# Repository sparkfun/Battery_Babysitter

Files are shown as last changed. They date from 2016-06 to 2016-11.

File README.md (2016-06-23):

SparkFun Battery Babysitter
========================================

SparkFun Battery Babysitter (https://www.sparkfun.com/products/13777)

[*SparkFun Battery Babysitter (PRT-13777)*](https://www.sparkfun.com/products/13777)

The [SparkFun Battery Babysitter](https://www.sparkfun.com/products/13777) is an all-in-one single-cell lithium polymer (LiPo) battery manager. It’s half **battery-charger**, half **battery monitor**, and it’s all you’ll ever need to keep your battery-powered project running safely and extensively.

The Battery Babysitter features a pair of Texas Instruments LiPo-management IC’s: a [BQ24075 battery charger](http://www.ti.com/product/BQ24075) and a [BQ27441-G1A fuel gauge](http://www.ti.com/product/BQ27441-G1). The BQ24075 supports adjustable charge rates up to 1.5A, as well as USB-compliant 100mA and 500mA options. It also features power-path management, guaranteeing reliable power to your project.

The self-calibrating, I2C-based BQ27441-G1A measures your battery’s voltage to estimate its charge percentage and remaining capacity. The chip is also hooked up to a current-sensing resistor, which allows it to measure current and power! It’s a handy IC to have, especially if you ever need to keep an extra eye on your project’s power draw.

Repository Contents
-------------------

* **/Documentation** - Data sheets, additional product information
* **/Hardware** - Eagle design files (.brd, .sch)
* **/Libraries** - Libraries for use with the Battery Babysitter
* **/Production** - Production panel files (.brd)

Documentation
--------------
* **[BQ27441 LiPo Fuel Gauge Arduino Library](https://github.com/sparkfun/SparkFun_BQ27441_Arduino_Library)** - Arduino library for the Battery Babysitter's BQ27441-G1A LiPo Fuel Gauge.
* **[Hookup Guide](https://learn.sparkfun.com/tutorials/battery-babysitter-hookup-guide)** - Basic hookup guide for the Battery Babysitter.
* **[SparkFun Fritzing repo](https://github.com/sparkfun/Fritzing_Parts)** - Fritzing diagrams for SparkFun products.
* **[SparkFun 3D Model repo](https://github.com/sparkfun/3D_Models)** - 3D models of SparkFun products. 
* **[SparkFun Graphical Datasheets](https://github.com/sparkfun/Graphical_Datasheets)** -Graphical Datasheets for various SparkFun products.

Product Versions
----------------
* [Battery Babysitter v1.0 (PRT-13777)](https://www.sparkfun.com/products/13777)- Initial release of the SparkFun Battery Babysitter.

Version History
---------------
* [1.0](https://github.com/sparkfun/Battery_Babysitter/releases/tag/V_1.0) - v1.0 Hardware release

License Information
-------------------

This product is _**open source**_! 

Please review the LICENSE.md file for license information. 

If you have any questions or concerns on licensing, please contact techsupport@sparkfun.com.

Distributed as-is; no warranty is given.

- Your friends at SparkFun.

_<COLLABORATION CREDIT>_

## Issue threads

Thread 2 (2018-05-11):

EN1 & EN2 Operation Description

dwgibbons, 2018-05-11:
The operational description of EN1 and EN2 appears to be wrong in both the documentation and schematic. The datasheet describes their use as "EN1 and EN2 control the maximum input current" on page 5. (ILIM, not ISET).

I've been staring at datasheets a lot longer than usual today. Please let me know if I'm wrong.

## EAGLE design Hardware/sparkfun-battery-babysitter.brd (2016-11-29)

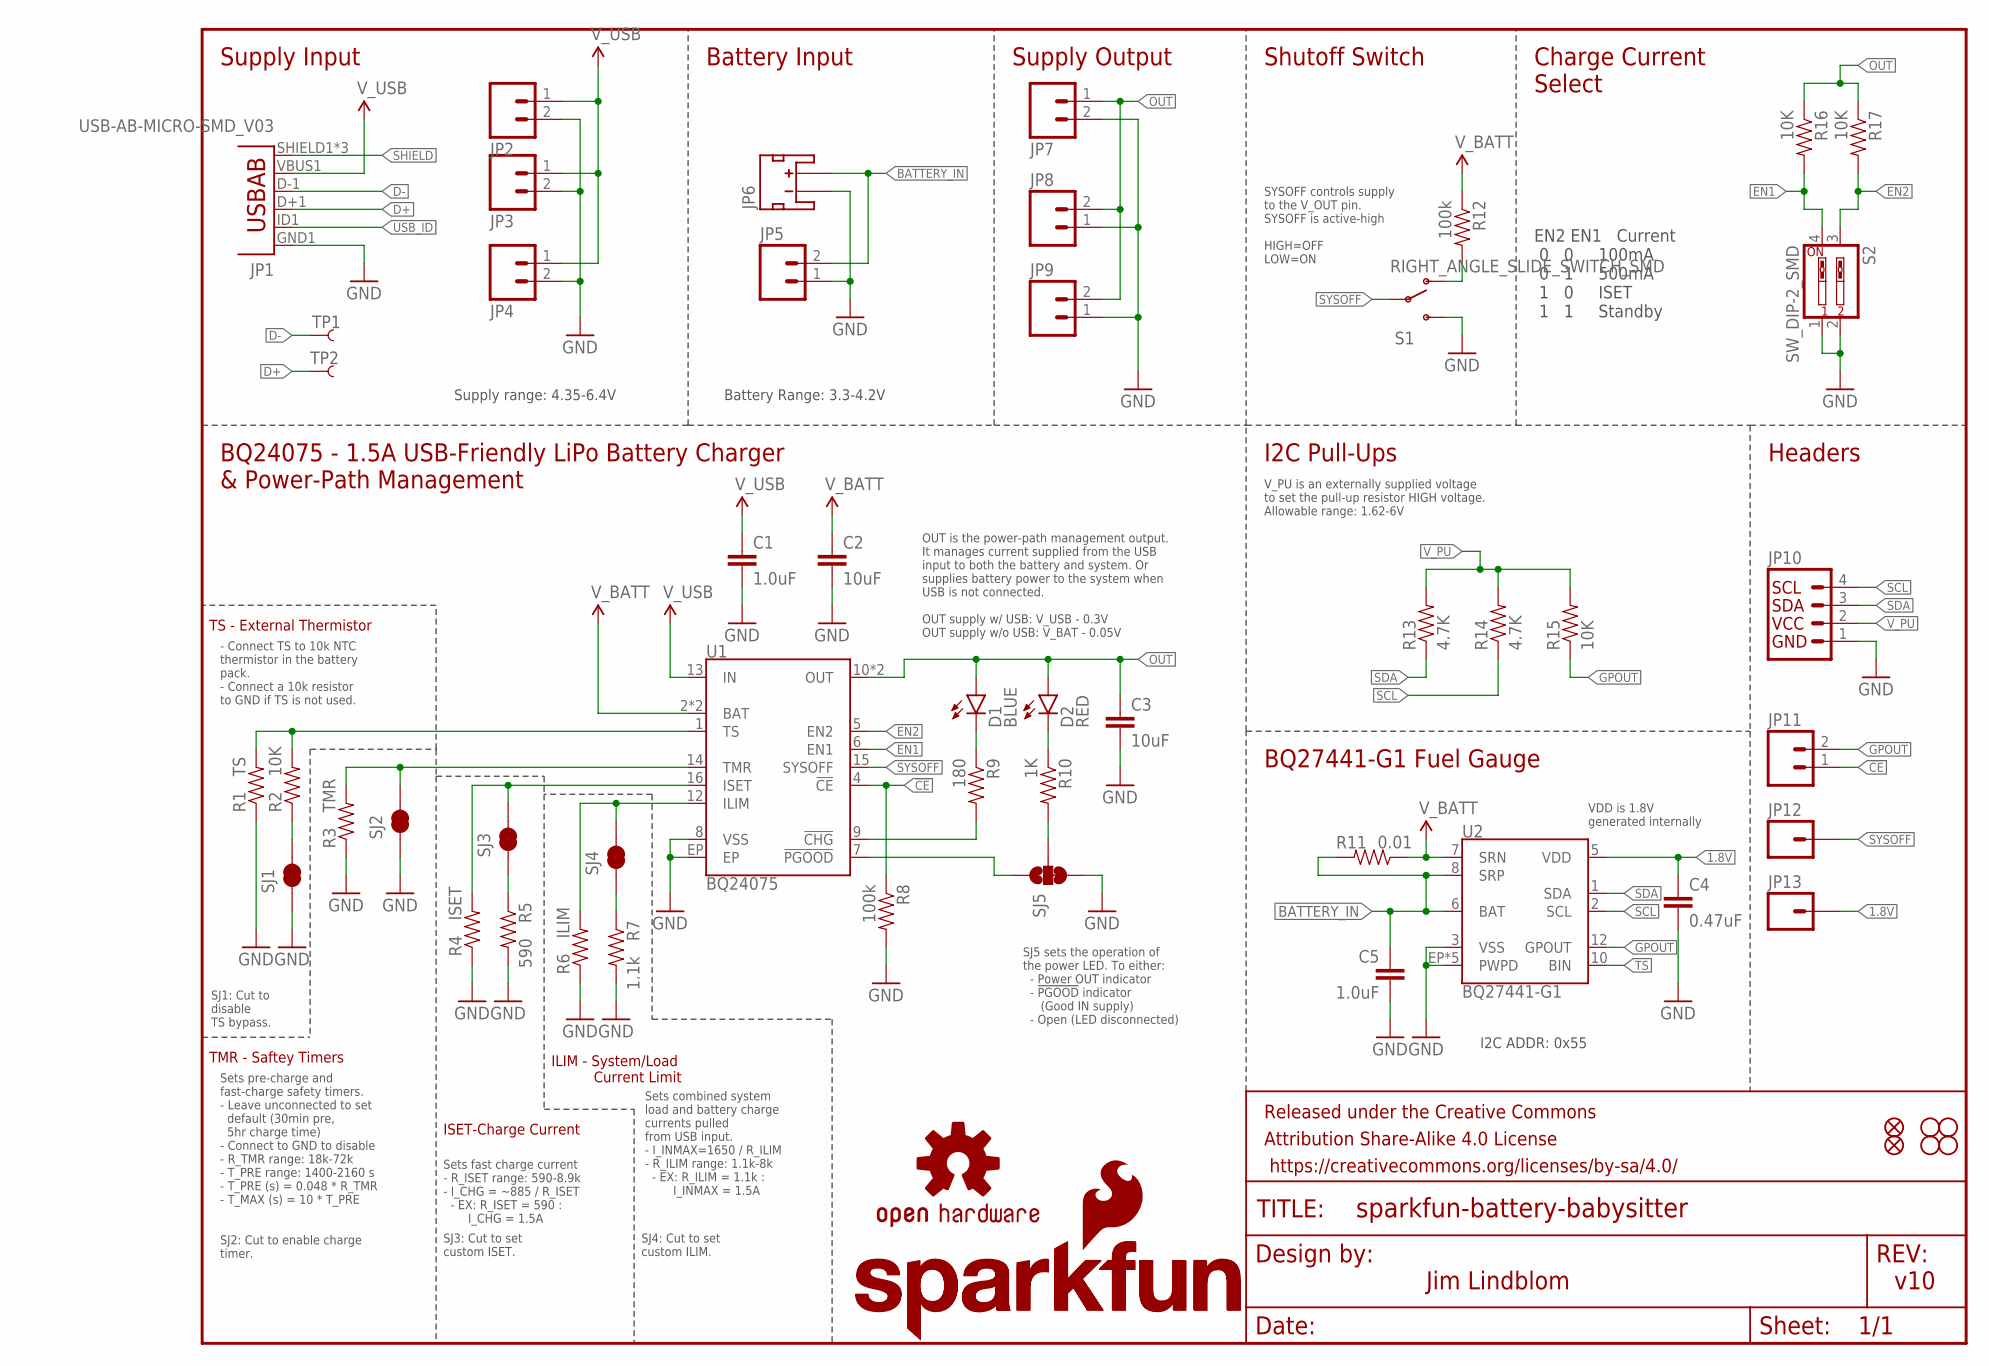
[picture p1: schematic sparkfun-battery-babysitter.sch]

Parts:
C1: 1.0uF; 1206-CAP
C2, C3: 10uF; 0805-CAP
C4: 0.47uF; 0603-CAP
C5: 1.0uF; 0603-CAP
D1: BLUE; LED-0603
D2: RED; LED-0603
FID1, FID2: FIDUCIAL1X2; FIDUCIAL-1X2
FRAME1: FRAME-LETTER; CREATIVE_COMMONS
JP1: USB-AB-MICRO-SMD_V03
JP2, JP4, JP5, JP8, JP11: M021X02_NO_SILK; 1X02_NO_SILK
JP3, JP7: M023.5MM-NO_SILK; SCREWTERMINAL-3.5MM-2-NS
JP6: JST_2MM_MALE; JST-2-SMD
JP9: M02-JST-2-PTH-NO_SILK; JST-2-PTH-NS
JP10: I2C_STANDARD_NO_SILK; 1X04_NO_SILK
JP12, JP13: M01PTH_NO_SILK_YES_STOP; 1X01_NO_SILK
LOGO1: SFE_LOGO_NAME.1_INCH; SFE_LOGO_NAME_.1
LOGO2: SFE_LOGO_NAME_FLAME.1_INCH; SFE_LOGO_NAME_FLAME_.1
LOGO3: OSHW-LOGOS; OSHW-LOGO-S
R1: TS; 1/6W-RES
R2, R15, R16, R17: 10K; 0603-RES
R3: TMR; 1/6W-RES
R4: ISET; 1/6W-RES
R5: 590; 0603-RES
R6: ILIM; 1/6W-RES
R7: 1.1k; 0603-RES
R8, R12: 100k; 0603-RES
R9: 180; 0603-RES
R10: 1K; 0603-RES
R11: 0.01; 1206
R13, R14: 4.7K; 0603-RES
S1: RIGHT_ANGLE_SLIDE_SWITCH_SMD; SWITCH-SPST-SMD-A
S2: SW_DIP-2_SMD; DIPSWITCH-02-50MIL
SJ1, SJ2, SJ3, SJ4: JUMPER-PAD-2-NC_BY_TRACE; PAD-JUMPER-2-NC_BY_TRACE_YES_SILK
SJ5: JUMPER-PAD-3-2OF3_NC_BY_TRACE_SMALL; PAD-JUMPER-3-2OF3_NC_BY_TRACE_YES_SILK_FULL_BOX
STANDOFF1, STANDOFF2, STANDOFF3, STANDOFF4: STAND-OFF
TP1, TP2: TEST-POINT3X4; PAD.03X.04
U1: BQ24075; PVQFN-N16
U2: BQ27441-G1; PDSO-N12

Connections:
1.8V: C4.1, JP13.1, U2.5 (VDD)
!CE!: JP11.1, R8.1, U1.4 (!CE!)
!CHG!: R9.2, U1.9 (!CHG!)
!PGOOD!: SJ5.1, U1.7 (!PGOOD!)
BATTERY_IN: C5.1, JP5.2, JP6.2 (+), R11.2, U2.6 (BAT), U2.8 (SRP)
D+: JP1.D+1 (D+), TP2.P$1
D-: JP1.D-1 (D-), TP1.P$1
EN1: R16.2, S2.4, U1.6 (EN1)
EN2: R17.2, S2.3, U1.5 (EN2)
GND: C1.2, C2.2, C3.2, C4.2, C5.2, JP1.GND1 (GND), JP2.2, JP3.2, JP4.2, JP5.1, JP6.1 (-), JP7.2, JP8.1, JP9.1, JP10.1, R1.1, R3.1, R4.1, R5.2, R6.1, R7.2, R8.2, S1.3 (S), S2.1, S2.2, SJ1.1, SJ2.1, SJ5.3, U1.8 (VSS), U1.EP, U2.3 (VSS), U2.EP (PWPD), U2.EP1 (PWPD), U2.EP2 (PWPD), U2.EP3 (PWPD), U2.EP4 (PWPD)
GPOUT: JP11.2, R15.1, U2.12 (GPOUT)
ILIM: R6.2, SJ4.2, U1.12 (ILIM)
ISET: R4.2, SJ3.2, U1.16 (ISET)
unnamed: R2.1, SJ1.2
unnamed: R7.1, SJ4.1
unnamed: R5.1, SJ3.1
unnamed: R12.2, S1.1 (O)
unnamed: R10.2, SJ5.2
unnamed: D1.C, R9.1
unnamed: D2.C, R10.1
OUT: C3.1, D1.A, D2.A, JP7.1, JP8.2, JP9.2, R16.1, R17.1, U1.10 (OUT), U1.11 (OUT)
SCL: JP10.4, R14.1, U2.2 (SCL)
SDA: JP10.3, R13.1, U2.1 (SDA)
SHIELD: JP1.SHIELD1 (SHIELD), JP1.SHIELD2 (SHIELD), JP1.SHIELD3 (SHIELD)
SYSOFF: JP12.1, S1.2, U1.15 (SYSOFF)
TMR: R3.2, SJ2.2, U1.14 (TMR)
TS: R1.2, R2.2, U1.1 (TS), U2.10 (BIN)
USB_ID: JP1.ID1 (USBID)
V_BATT: C2.1, R11.1, R12.1, U1.2 (BAT), U1.3 (BAT), U2.7 (SRN)
V_PU: JP10.2, R13.2, R14.2, R15.2
V_USB: C1.1, JP1.VBUS1 (VBUS), JP2.1, JP3.1, JP4.1, U1.13 (IN)

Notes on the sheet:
EN2 EN1 Current 0 0 100mA 0 1 500mA 1 0 ISET 1 1 Standby
Sets fast charge current - R_ISET range: 590-8.9k - I_CHG = ~885 / R_ISET - EX: R_ISET = 590 : I_CHG = 1.5A
Sets combined system load and battery charge currents pulled from USB input. - I_INMAX=1650 / R_ILIM - R_ILIM range: 1.1k-8k - EX: R_ILIM = 1.1k : I_INMAX = 1.5A
Supply Input
Battery Input
Supply Output
Shutoff Switch
Charge Current Select
BQ24075 - 1.5A USB-Friendly LiPo Battery Charger & Power-Path Management
I2C Pull-Ups
BQ27441-G1 Fuel Gauge
Headers
Jim Lindblom
v10
SYSOFF controls supply to the V_OUT pin. SYSOFF is active-high HIGH=OFF LOW=ON
SJ1: Cut to disable TS bypass.
SJ3: Cut to set custom ISET.
SJ4: Cut to set custom ILIM.
ILIM - System/Load Current Limit
ISET-Charge Current
TMR - Saftey Timers
Sets pre-charge and fast-charge safety timers. - Leave unconnected to set default (30min pre, 5hr charge time) - Connect to GND to disable - R_TMR range: 18k-72k - T_PRE range: 1400-2160 s - T_PRE (s) = 0.048 * R_TMR - T_MAX (s) = 10 * T_PRE
SJ2: Cut to enable charge timer.
TS - External Thermistor
- Connect TS to 10k NTC thermistor in the battery pack. - Connect a 10k resistor to GND if TS is not used.
V_PU is an externally supplied voltage to set the pull-up resistor HIGH voltage. Allowable range: 1.62-6V
Supply range: 4.35-6.4V
VDD is 1.8V generated internally
OUT is the power-path management output. It manages current supplied from the USB input to both the battery and system. Or supplies battery power to the system when USB is not connected. OUT supply w/ USB: V_USB - 0.3V OUT supply w/o USB: V_BAT - 0.05V
I2C ADDR: 0x55
SJ5 sets the operation of the power LED. To either: - Power OUT indicator - !PGOOD! indicator (Good IN supply) - Open (LED disconnected)
Battery Range: 3.3-4.2V

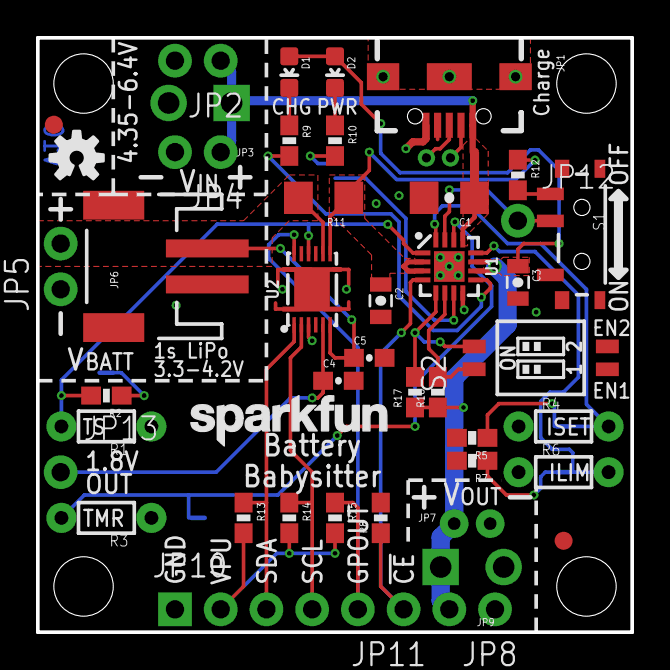
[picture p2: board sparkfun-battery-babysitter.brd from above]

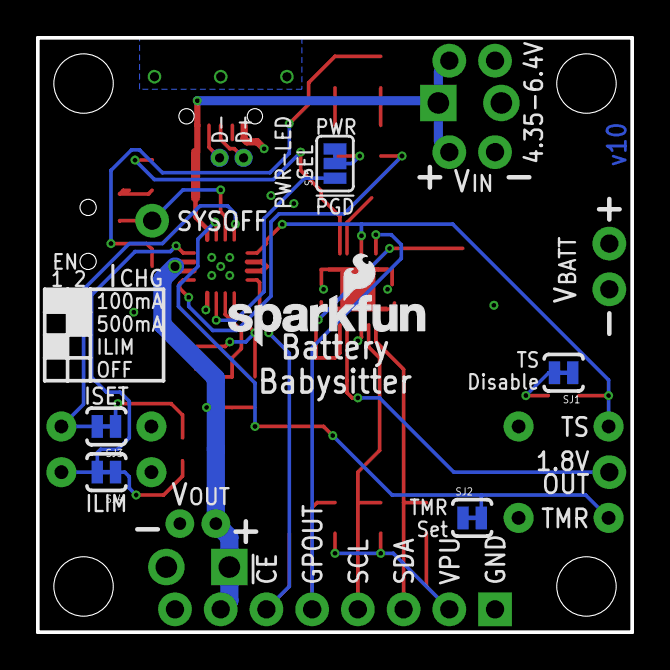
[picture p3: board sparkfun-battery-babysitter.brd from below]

Board: 2 copper layers, 33.0 x 33.0 mm, 58 parts (8 on the bottom side), 30 nets.

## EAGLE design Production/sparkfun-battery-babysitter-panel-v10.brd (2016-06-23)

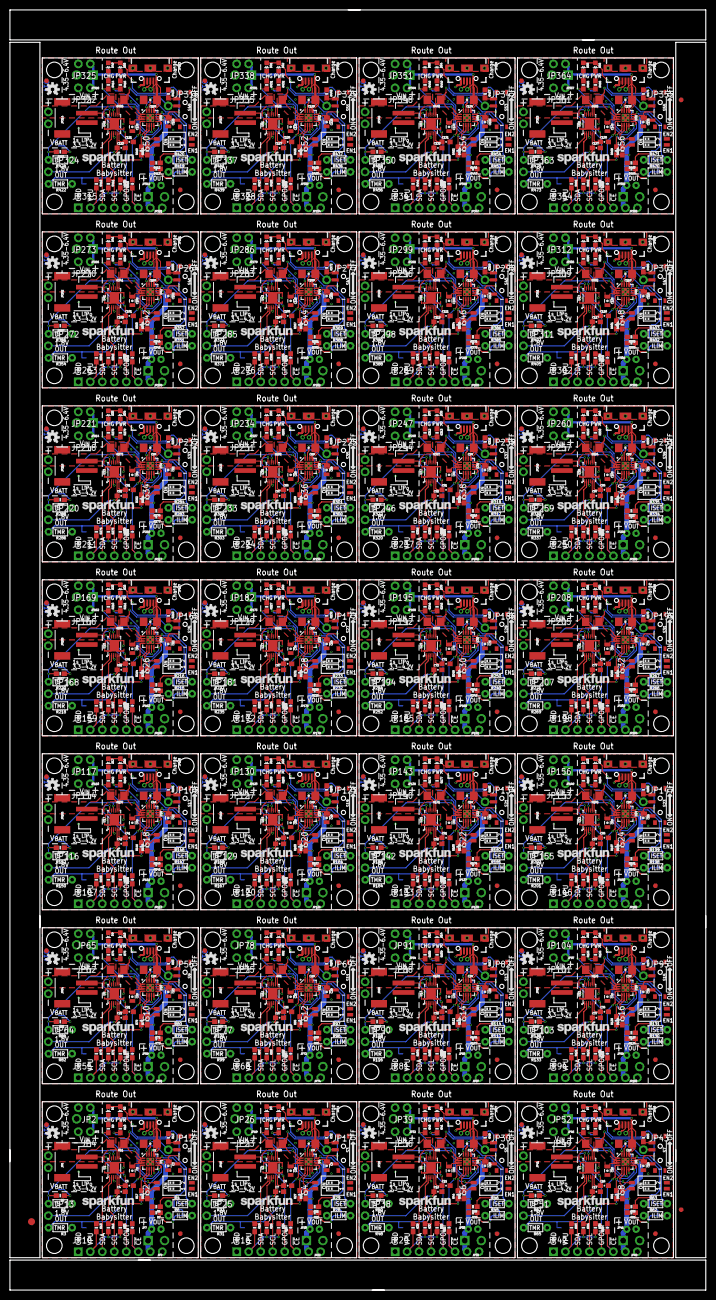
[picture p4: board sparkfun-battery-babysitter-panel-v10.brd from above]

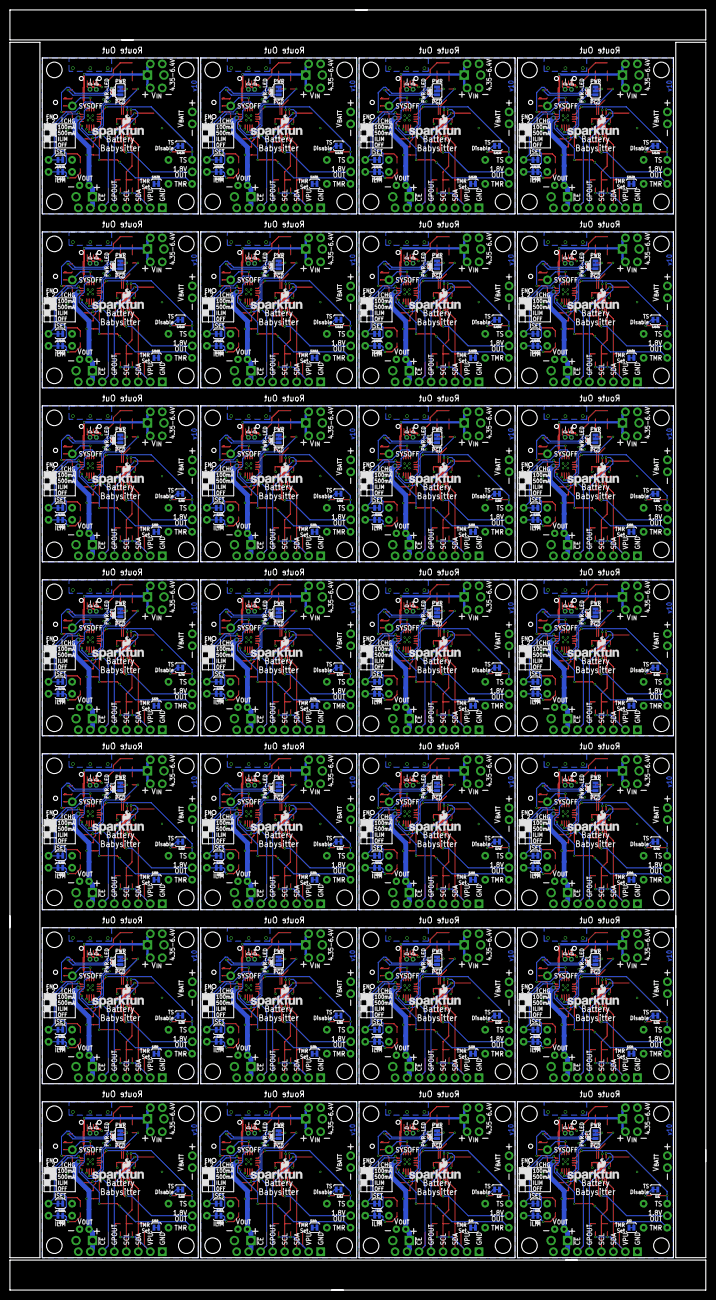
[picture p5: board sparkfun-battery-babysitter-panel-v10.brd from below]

Board: 2 copper layers, 147.3 x 271.0 mm, 1599 parts (224 on the bottom side), 840 nets.

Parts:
C1, C9, C14, C19, C24, C29, C34, C39, C44, C49, C54, C59, C64, C69, C74, C79, C84, C89, C94, C99, C104, C109, C114, C119, C124, C129, C134, C139: 1.0uF; 1206-CAP
C2, C3, C8, C10, C13, C15, C18, C20, C23, C25, C28, C30, C33, C35, C38, C40, C43, C45, C48, C50, C53, C55, C58, C60, C63, C65, C68, C70, C73, C75, C78, C80, C83, C85, C88, C90, C93, C95, C98, C100, C103, C105, C108, C110, C113, C115, C118, C120, C123, C125, C128, C130, C133, C135, C138, C140: 10uF; 0805-CAP
C4, C7, C12, C17, C22, C27, C32, C37, C42, C47, C52, C57, C62, C67, C72, C77, C82, C87, C92, C97, C102, C107, C112, C117, C122, C127, C132, C137: 0.47uF; 0603-CAP
C5, C6, C11, C16, C21, C26, C31, C36, C41, C46, C51, C56, C61, C66, C71, C76, C81, C86, C91, C96, C101, C106, C111, C116, C121, C126, C131, C136: 1.0uF; 0603-CAP
D1, D3, D5, D7, D9, D11, D13, D15, D17, D19, D21, D23, D25, D27, D29, D31, D33, D35, D37, D39, D41, D43, D45, D47, D49, D51, D53, D55: BLUE; LED-0603
D2, D4, D6, D8, D10, D12, D14, D16, D18, D20, D22, D24, D26, D28, D30, D32, D34, D36, D38, D40, D42, D44, D46, D48, D50, D52, D54, D56: RED; LED-0603
E$1: FIDUCIAL-1.5X3
E$5, E$6: FIDUCIAL-1X2
FID1, FID2, FID3, FID4, FID5, FID6, FID7, FID8, FID9, FID10, FID11, FID12, FID13, FID14, FID15, FID16, FID17, FID18, FID19, FID20, FID21, FID22, FID23, FID24, FID25, FID26, FID27, FID28, FID29, FID30, FID31, FID32, FID33, FID34, FID35, FID36, FID37, FID38, FID39, FID40, FID41, FID42, FID43, FID44, FID45, FID46, FID47, FID48, FID49, FID50, FID51, FID52, FID53, FID54, FID55, FID56: FIDUCIAL1X2; FIDUCIAL-1X2
JP1, JP14, JP27, JP40, JP53, JP66, JP79, JP92, JP105, JP118, JP131, JP144, JP157, JP170, JP183, JP196, JP209, JP222, JP235, JP248, JP261, JP274, JP287, JP300, JP313, JP326, JP339, JP352: USB-AB-MICRO-SMD_V03
JP2, JP4, JP5, JP8, JP11, JP18, JP21, JP23, JP24, JP26, JP31, JP34, JP36, JP37, JP39, JP44, JP47, JP49, JP50, JP52, JP57, JP60, JP62, JP63, JP65, JP70, JP73, JP75, JP76, JP78, JP83, JP86, JP88, JP89, JP91, JP96, JP99, JP101, JP102, JP104, JP109, JP112, JP114, JP115, JP117, JP122, JP125, JP127, JP128, JP130, JP135, JP138, JP140, JP141, JP143, JP148, JP151, JP153, JP154, JP156, JP161, JP164, JP166, JP167, JP169, JP174, JP177, JP179, JP180, JP182, JP187, JP190, JP192, JP193, JP195, JP200, JP203, JP205, JP206, JP208, JP213, JP216, JP218, JP219, JP221, JP226, JP229, JP231, JP232, JP234, JP239, JP242, JP244, JP245, JP247, JP252, JP255, JP257, JP258, JP260, JP265, JP268, JP270, JP271, JP273, JP278, JP281, JP283, JP284, JP286, JP291, JP294, JP296, JP297, JP299, JP304, JP307, JP309, JP310, JP312, JP317, JP320, JP322, JP323, JP325, JP330, JP333, JP335, JP336, JP338, JP343, JP346, JP348, JP349, JP351, JP356, JP359, JP361, JP362, JP364: 1X02_NO_SILK
JP3, JP7, JP19, JP20, JP32, JP33, JP45, JP46, JP58, JP59, JP71, JP72, JP84, JP85, JP97, JP98, JP110, JP111, JP123, JP124, JP136, JP137, JP149, JP150, JP162, JP163, JP175, JP176, JP188, JP189, JP201, JP202, JP214, JP215, JP227, JP228, JP240, JP241, JP253, JP254, JP266, JP267, JP279, JP280, JP292, JP293, JP305, JP306, JP318, JP319, JP331, JP332, JP344, JP345, JP357, JP358: SCREWTERMINAL-3.5MM-2-NS
JP6, JP15, JP28, JP41, JP54, JP67, JP80, JP93, JP106, JP119, JP132, JP145, JP158, JP171, JP184, JP197, JP210, JP223, JP236, JP249, JP262, JP275, JP288, JP301, JP314, JP327, JP340, JP353: JST-2-SMD
JP9, JP22, JP35, JP48, JP61, JP74, JP87, JP100, JP113, JP126, JP139, JP152, JP165, JP178, JP191, JP204, JP217, JP230, JP243, JP256, JP269, JP282, JP295, JP308, JP321, JP334, JP347, JP360: JST-2-PTH-NS
JP10, JP16, JP29, JP42, JP55, JP68, JP81, JP94, JP107, JP120, JP133, JP146, JP159, JP172, JP185, JP198, JP211, JP224, JP237, JP250, JP263, JP276, JP289, JP302, JP315, JP328, JP341, JP354: 1X04_NO_SILK
JP12, JP13, JP17, JP25, JP30, JP38, JP43, JP51, JP56, JP64, JP69, JP77, JP82, JP90, JP95, JP103, JP108, JP116, JP121, JP129, JP134, JP142, JP147, JP155, JP160, JP168, JP173, JP181, JP186, JP194, JP199, JP207, JP212, JP220, JP225, JP233, JP238, JP246, JP251, JP259, JP264, JP272, JP277, JP285, JP290, JP298, JP303, JP311, JP316, JP324, JP329, JP337, JP342, JP350, JP355, JP363: 1X01_NO_SILK
LOGO1, LOGO4, LOGO7, LOGO10, LOGO13, LOGO16, LOGO19, LOGO22, LOGO25, LOGO28, LOGO31, LOGO34, LOGO37, LOGO40, LOGO43, LOGO46, LOGO49, LOGO52, LOGO55, LOGO58, LOGO61, LOGO64, LOGO67, LOGO70, LOGO73, LOGO76, LOGO79, LOGO82: SFE_LOGO_NAME.1_INCH; SFE_LOGO_NAME_.1
LOGO2, LOGO6, LOGO9, LOGO12, LOGO15, LOGO18, LOGO21, LOGO24, LOGO27, LOGO30, LOGO33, LOGO36, LOGO39, LOGO42, LOGO45, LOGO48, LOGO51, LOGO54, LOGO57, LOGO60, LOGO63, LOGO66, LOGO69, LOGO72, LOGO75, LOGO78, LOGO81, LOGO84: SFE_LOGO_NAME_FLAME.1_INCH; SFE_LOGO_NAME_FLAME_.1
LOGO3, LOGO5, LOGO8, LOGO11, LOGO14, LOGO17, LOGO20, LOGO23, LOGO26, LOGO29, LOGO32, LOGO35, LOGO38, LOGO41, LOGO44, LOGO47, LOGO50, LOGO53, LOGO56, LOGO59, LOGO62, LOGO65, LOGO68, LOGO71, LOGO74, LOGO77, LOGO80, LOGO83: OSHW-LOGOS; OSHW-LOGO-S
R1, R33, R50, R67, R84, R101, R118, R135, R152, R169, R186, R203, R220, R237, R254, R271, R288, R305, R322, R339, R356, R373, R390, R407, R424, R441, R458, R475: TS; 1/6W-RES
R2, R15, R16, R17, R26, R27, R30, R34, R43, R44, R47, R51, R60, R61, R64, R68, R77, R78, R81, R85, R94, R95, R98, R102, R111, R112, R115, R119, R128, R129, R132, R136, R145, R146, R149, R153, R162, R163, R166, R170, R179, R180, R183, R187, R196, R197, R200, R204, R213, R214, R217, R221, R230, R231, R234, R238, R247, R248, R251, R255, R264, R265, R268, R272, R281, R282, R285, R289, R298, R299, R302, R306, R315, R316, R319, R323, R332, R333, R336, R340, R349, R350, R353, R357, R366, R367, R370, R374, R383, R384, R387, R391, R400, R401, R404, R408, R417, R418, R421, R425, R434, R435, R438, R442, R451, R452, R455, R459, R468, R469, R472, R476: 10K; 0603-RES
R3, R31, R48, R65, R82, R99, R116, R133, R150, R167, R184, R201, R218, R235, R252, R269, R286, R303, R320, R337, R354, R371, R388, R405, R422, R439, R456, R473: TMR; 1/6W-RES
R4, R29, R46, R63, R80, R97, R114, R131, R148, R165, R182, R199, R216, R233, R250, R267, R284, R301, R318, R335, R352, R369, R386, R403, R420, R437, R454, R471: ISET; 1/6W-RES
R5, R21, R38, R55, R72, R89, R106, R123, R140, R157, R174, R191, R208, R225, R242, R259, R276, R293, R310, R327, R344, R361, R378, R395, R412, R429, R446, R463: 590; 0603-RES
R6, R28, R45, R62, R79, R96, R113, R130, R147, R164, R181, R198, R215, R232, R249, R266, R283, R300, R317, R334, R351, R368, R385, R402, R419, R436, R453, R470: ILIM; 1/6W-RES
R7, R22, R39, R56, R73, R90, R107, R124, R141, R158, R175, R192, R209, R226, R243, R260, R277, R294, R311, R328, R345, R362, R379, R396, R413, R430, R447, R464: 1.1k; 0603-RES
R8, R12, R25, R32, R42, R49, R59, R66, R76, R83, R93, R100, R110, R117, R127, R134, R144, R151, R161, R168, R178, R185, R195, R202, R212, R219, R229, R236, R246, R253, R263, R270, R280, R287, R297, R304, R314, R321, R331, R338, R348, R355, R365, R372, R382, R389, R399, R406, R416, R423, R433, R440, R450, R457, R467, R474: 100k; 0603-RES
R9, R23, R40, R57, R74, R91, R108, R125, R142, R159, R176, R193, R210, R227, R244, R261, R278, R295, R312, R329, R346, R363, R380, R397, R414, R431, R448, R465: 180; 0603-RES
R10, R24, R41, R58, R75, R92, R109, R126, R143, R160, R177, R194, R211, R228, R245, R262, R279, R296, R313, R330, R347, R364, R381, R398, R415, R432, R449, R466: 1K; 0603-RES
R11, R18, R35, R52, R69, R86, R103, R120, R137, R154, R171, R188, R205, R222, R239, R256, R273, R290, R307, R324, R341, R358, R375, R392, R409, R426, R443, R460: 0.01; 1206
R13, R14, R19, R20, R36, R37, R53, R54, R70, R71, R87, R88, R104, R105, R121, R122, R138, R139, R155, R156, R172, R173, R189, R190, R206, R207, R223, R224, R240, R241, R257, R258, R274, R275, R291, R292, R308, R309, R325, R326, R342, R343, R359, R360, R376, R377, R393, R394, R410, R411, R427, R428, R444, R445, R461, R462: 4.7K; 0603-RES
S1, S3, S5, S7, S9, S11, S13, S15, S17, S19, S21, S23, S25, S27, S29, S31, S33, S35, S37, S39, S41, S43, S45, S47, S49, S51, S53, S55: SWITCH-SPST-SMD-A
S2, S4, S6, S8, S10, S12, S14, S16, S18, S20, S22, S24, S26, S28, S30, S32, S34, S36, S38, S40, S42, S44, S46, S48, S50, S52, S54, S56: DIPSWITCH-02-50MIL
SJ1, SJ2, SJ3, SJ4, SJ6, SJ7, SJ8, SJ9, SJ11, SJ12, SJ13, SJ14, SJ16, SJ17, SJ18, SJ19, SJ21, SJ22, SJ23, SJ24, SJ26, SJ27, SJ28, SJ29, SJ31, SJ32, SJ33, SJ34, SJ36, SJ37, SJ38, SJ39, SJ41, SJ42, SJ43, SJ44, SJ46, SJ47, SJ48, SJ49, SJ51, SJ52, SJ53, SJ54, SJ56, SJ57, SJ58, SJ59, SJ61, SJ62, SJ63, SJ64, SJ66, SJ67, SJ68, SJ69, SJ71, SJ72, SJ73, SJ74, SJ76, SJ77, SJ78, SJ79, SJ81, SJ82, SJ83, SJ84, SJ86, SJ87, SJ88, SJ89, SJ91, SJ92, SJ93, SJ94, SJ96, SJ97, SJ98, SJ99, SJ101, SJ102, SJ103, SJ104, SJ106, SJ107, SJ108, SJ109, SJ111, SJ112, SJ113, SJ114, SJ116, SJ117, SJ118, SJ119, SJ121, SJ122, SJ123, SJ124, SJ126, SJ127, SJ128, SJ129, SJ131, SJ132, SJ133, SJ134, SJ136, SJ137, SJ138, SJ139: PAD-JUMPER-2-NC_BY_TRACE_YES_SILK
SJ5, SJ10, SJ15, SJ20, SJ25, SJ30, SJ35, SJ40, SJ45, SJ50, SJ55, SJ60, SJ65, SJ70, SJ75, SJ80, SJ85, SJ90, SJ95, SJ100, SJ105, SJ110, SJ115, SJ120, SJ125, SJ130, SJ135, SJ140: PAD-JUMPER-3-2OF3_NC_BY_TRACE_YES_SILK_FULL_BOX
STANDOFF1, STANDOFF2, STANDOFF3, STANDOFF4, STANDOFF5, STANDOFF6, STANDOFF7, STANDOFF8, STANDOFF9, STANDOFF10, STANDOFF11, STANDOFF12, STANDOFF13, STANDOFF14, STANDOFF15, STANDOFF16, STANDOFF17, STANDOFF18, STANDOFF19, STANDOFF20, STANDOFF21, STANDOFF22, STANDOFF23, STANDOFF24, STANDOFF25, STANDOFF26, STANDOFF27, STANDOFF28, STANDOFF29, STANDOFF30, STANDOFF31, STANDOFF32, STANDOFF33, STANDOFF34, STANDOFF35, STANDOFF36, STANDOFF37, STANDOFF38, STANDOFF39, STANDOFF40, STANDOFF41, STANDOFF42, STANDOFF43, STANDOFF44, STANDOFF45, STANDOFF46, STANDOFF47, STANDOFF48, STANDOFF49, STANDOFF50, STANDOFF51, STANDOFF52, STANDOFF53, STANDOFF54, STANDOFF55, STANDOFF56, STANDOFF57, STANDOFF58, STANDOFF59, STANDOFF60, STANDOFF61, STANDOFF62, STANDOFF63, STANDOFF64, STANDOFF65, STANDOFF66, STANDOFF67, STANDOFF68, STANDOFF69, STANDOFF70, STANDOFF71, STANDOFF72, STANDOFF73, STANDOFF74, STANDOFF75, STANDOFF76, STANDOFF77, STANDOFF78, STANDOFF79, STANDOFF80, STANDOFF81, STANDOFF82, STANDOFF83, STANDOFF84, STANDOFF85, STANDOFF86, STANDOFF87, STANDOFF88, STANDOFF89, STANDOFF90, STANDOFF91, STANDOFF92, STANDOFF93, STANDOFF94, STANDOFF95, STANDOFF96, STANDOFF97, STANDOFF98, STANDOFF99, STANDOFF100, STANDOFF101, STANDOFF102, STANDOFF103, STANDOFF104, STANDOFF105, STANDOFF106, STANDOFF107, STANDOFF108, STANDOFF109, STANDOFF110, STANDOFF111, STANDOFF112: STAND-OFF
TP1, TP2, TP3, TP4, TP5, TP6, TP7, TP8, TP9, TP10, TP11, TP12, TP13, TP14, TP15, TP16, TP17, TP18, TP19, TP20, TP21, TP22, TP23, TP24, TP25, TP26, TP27, TP28, TP29, TP30, TP31, TP32, TP33, TP34, TP35, TP36, TP37, TP38, TP39, TP40, TP41, TP42, TP43, TP44, TP45, TP46, TP47, TP48, TP49, TP50, TP51, TP52, TP53, TP54, TP55, TP56: PAD.03X.04
U1, U4, U6, U8, U10, U12, U14, U16, U18, U20, U22, U24, U26, U28, U30, U32, U34, U36, U38, U40, U42, U44, U46, U48, U50, U52, U54, U56: BQ24075; PVQFN-N16
U2, U3, U5, U7, U9, U11, U13, U15, U17, U19, U21, U23, U25, U27, U29, U31, U33, U35, U37, U39, U41, U43, U45, U47, U49, U51, U53, U55: BQ27441-G1; PDSO-N12

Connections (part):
1.8V: C4.1, JP13.1, U2.5
1.8V1: C7.1, JP25.1, U3.5
1.8V2: C12.1, JP38.1, U5.5
1.8V3: C17.1, JP51.1, U7.5
1.8V4: C22.1, JP64.1, U9.5
1.8V5: C27.1, JP77.1, U11.5
1.8V6: C32.1, JP90.1, U13.5
1.8V7: C37.1, JP103.1, U15.5
1.8V8: C42.1, JP116.1, U17.5
1.8V9: C47.1, JP129.1, U19.5
1.8V10: C52.1, JP142.1, U21.5
1.8V11: C57.1, JP155.1, U23.5
1.8V12: C62.1, JP168.1, U25.5
1.8V13: C67.1, JP181.1, U27.5
1.8V14: C72.1, JP194.1, U29.5
1.8V15: C77.1, JP207.1, U31.5
1.8V16: C82.1, JP220.1, U33.5
1.8V17: C87.1, JP233.1, U35.5
1.8V18: C92.1, JP246.1, U37.5
1.8V19: C97.1, JP259.1, U39.5
1.8V20: C102.1, JP272.1, U41.5
1.8V21: C107.1, JP285.1, U43.5
1.8V22: C112.1, JP298.1, U45.5
1.8V23: C117.1, JP311.1, U47.5
1.8V24: C122.1, JP324.1, U49.5
1.8V25: C127.1, JP337.1, U51.5
1.8V26: C132.1, JP350.1, U53.5
1.8V27: C137.1, JP363.1, U55.5
!CE!: JP11.1, R8.1, U1.4
!CE!1: JP24.1, R25.1, U4.4
!CE!2: JP37.1, R42.1, U6.4
!CE!3: JP50.1, R59.1, U8.4
!CE!4: JP63.1, R76.1, U10.4
!CE!5: JP76.1, R93.1, U12.4
!CE!6: JP89.1, R110.1, U14.4
!CE!7: JP102.1, R127.1, U16.4
!CE!8: JP115.1, R144.1, U18.4
!CE!9: JP128.1, R161.1, U20.4
!CE!10: JP141.1, R178.1, U22.4
!CE!11: JP154.1, R195.1, U24.4
!CE!12: JP167.1, R212.1, U26.4
!CE!13: JP180.1, R229.1, U28.4
!CE!14: JP193.1, R246.1, U30.4
!CE!15: JP206.1, R263.1, U32.4
!CE!16: JP219.1, R280.1, U34.4
!CE!17: JP232.1, R297.1, U36.4
!CE!18: JP245.1, R314.1, U38.4
!CE!19: JP258.1, R331.1, U40.4
!CE!20: JP271.1, R348.1, U42.4
!CE!21: JP284.1, R365.1, U44.4
!CE!22: JP297.1, R382.1, U46.4
!CE!23: JP310.1, R399.1, U48.4
!CE!24: JP323.1, R416.1, U50.4
!CE!25: JP336.1, R433.1, U52.4
!CE!26: JP349.1, R450.1, U54.4
!CE!27: JP362.1, R467.1, U56.4
!CHG!: R9.2, U1.9
!CHG!1: R23.2, U4.9
!CHG!2: R40.2, U6.9
!CHG!3: R57.2, U8.9
!CHG!4: R74.2, U10.9
!CHG!5: R91.2, U12.9
!CHG!6: R108.2, U14.9
!CHG!7: R125.2, U16.9
!CHG!8: R142.2, U18.9
!CHG!9: R159.2, U20.9
!CHG!10: R176.2, U22.9
!CHG!11: R193.2, U24.9
!CHG!12: R210.2, U26.9
!CHG!13: R227.2, U28.9
!CHG!14: R244.2, U30.9
!CHG!15: R261.2, U32.9
!CHG!16: R278.2, U34.9
!CHG!17: R295.2, U36.9
!CHG!18: R312.2, U38.9
!CHG!19: R329.2, U40.9
!CHG!20: R346.2, U42.9
!CHG!21: R363.2, U44.9
!CHG!22: R380.2, U46.9
!CHG!23: R397.2, U48.9
!CHG!24: R414.2, U50.9
!CHG!25: R431.2, U52.9
!CHG!26: R448.2, U54.9
!CHG!27: R465.2, U56.9
!PGOOD!: SJ5.1, U1.7
!PGOOD!1: SJ10.1, U4.7
!PGOOD!2: SJ15.1, U6.7
!PGOOD!3: SJ20.1, U8.7
!PGOOD!4: SJ25.1, U10.7
!PGOOD!5: SJ30.1, U12.7
!PGOOD!6: SJ35.1, U14.7
!PGOOD!7: SJ40.1, U16.7
!PGOOD!8: SJ45.1, U18.7
!PGOOD!9: SJ50.1, U20.7
!PGOOD!10: SJ55.1, U22.7
!PGOOD!11: SJ60.1, U24.7
!PGOOD!12: SJ65.1, U26.7
!PGOOD!13: SJ70.1, U28.7
!PGOOD!14: SJ75.1, U30.7
!PGOOD!15: SJ80.1, U32.7
!PGOOD!16: SJ85.1, U34.7
!PGOOD!17: SJ90.1, U36.7
!PGOOD!18: SJ95.1, U38.7
!PGOOD!19: SJ100.1, U40.7
!PGOOD!20: SJ105.1, U42.7
!PGOOD!21: SJ110.1, U44.7
!PGOOD!22: SJ115.1, U46.7
!PGOOD!23: SJ120.1, U48.7
!PGOOD!24: SJ125.1, U50.7
!PGOOD!25: SJ130.1, U52.7
!PGOOD!26: SJ135.1, U54.7
!PGOOD!27: SJ140.1, U56.7
BATTERY_IN: C5.1, JP5.2, JP6.2, R11.2, U2.6, U2.8
BATTERY_IN1: C6.1, JP15.2, JP18.2, R18.2, U3.6, U3.8
BATTERY_IN2: C11.1, JP28.2, JP31.2, R35.2, U5.6, U5.8
BATTERY_IN3: C16.1, JP41.2, JP44.2, R52.2, U7.6, U7.8
BATTERY_IN4: C21.1, JP54.2, JP57.2, R69.2, U9.6, U9.8
BATTERY_IN5: C26.1, JP67.2, JP70.2, R86.2, U11.6, U11.8
BATTERY_IN6: C31.1, JP80.2, JP83.2, R103.2, U13.6, U13.8
BATTERY_IN7: C36.1, JP93.2, JP96.2, R120.2, U15.6, U15.8
BATTERY_IN8: C41.1, JP106.2, JP109.2, R137.2, U17.6, U17.8
BATTERY_IN9: C46.1, JP119.2, JP122.2, R154.2, U19.6, U19.8
BATTERY_IN10: C51.1, JP132.2, JP135.2, R171.2, U21.6, U21.8
BATTERY_IN11: C56.1, JP145.2, JP148.2, R188.2, U23.6, U23.8
BATTERY_IN12: C61.1, JP158.2, JP161.2, R205.2, U25.6, U25.8
BATTERY_IN13: C66.1, JP171.2, JP174.2, R222.2, U27.6, U27.8
BATTERY_IN14: C71.1, JP184.2, JP187.2, R239.2, U29.6, U29.8
BATTERY_IN15: C76.1, JP197.2, JP200.2, R256.2, U31.6, U31.8
BATTERY_IN16: C81.1, JP210.2, JP213.2, R273.2, U33.6, U33.8
BATTERY_IN17: C86.1, JP223.2, JP226.2, R290.2, U35.6, U35.8
BATTERY_IN18: C91.1, JP236.2, JP239.2, R307.2, U37.6, U37.8
BATTERY_IN19: C96.1, JP249.2, JP252.2, R324.2, U39.6, U39.8
BATTERY_IN20: C101.1, JP262.2, JP265.2, R341.2, U41.6, U41.8
BATTERY_IN21: C106.1, JP275.2, JP278.2, R358.2, U43.6, U43.8
BATTERY_IN22: C111.1, JP288.2, JP291.2, R375.2, U45.6, U45.8
BATTERY_IN23: C116.1, JP301.2, JP304.2, R392.2, U47.6, U47.8
BATTERY_IN24: C121.1, JP314.2, JP317.2, R409.2, U49.6, U49.8
BATTERY_IN25: C126.1, JP327.2, JP330.2, R426.2, U51.6, U51.8
BATTERY_IN26: C131.1, JP340.2, JP343.2, R443.2, U53.6, U53.8
BATTERY_IN27: C136.1, JP353.2, JP356.2, R460.2, U55.6, U55.8
D+: JP1.D+1, TP2.P$1
D+1: JP14.D+1, TP4.P$1
D+2: JP27.D+1, TP6.P$1
D+3: JP40.D+1, TP8.P$1
D+4: JP53.D+1, TP10.P$1
D+5: JP66.D+1, TP12.P$1
D+6: JP79.D+1, TP14.P$1
D+7: JP92.D+1, TP16.P$1
D+8: JP105.D+1, TP18.P$1
D+9: JP118.D+1, TP20.P$1
D+10: JP131.D+1, TP22.P$1
D+11: JP144.D+1, TP24.P$1
D+12: JP157.D+1, TP26.P$1
D+13: JP170.D+1, TP28.P$1
D+14: JP183.D+1, TP30.P$1
D+15: JP196.D+1, TP32.P$1
D+16: JP209.D+1, TP34.P$1
D+17: JP222.D+1, TP36.P$1
D+18: JP235.D+1, TP38.P$1
D+19: JP248.D+1, TP40.P$1
D+20: JP261.D+1, TP42.P$1
D+21: JP274.D+1, TP44.P$1
D+22: JP287.D+1, TP46.P$1
D+23: JP300.D+1, TP48.P$1
D+24: JP313.D+1, TP50.P$1
D+25: JP326.D+1, TP52.P$1
D+26: JP339.D+1, TP54.P$1
D+27: JP352.D+1, TP56.P$1
D-: JP1.D-1, TP1.P$1
D-1: JP14.D-1, TP3.P$1
D-2: JP27.D-1, TP5.P$1
D-3: JP40.D-1, TP7.P$1
D-4: JP53.D-1, TP9.P$1
D-5: JP66.D-1, TP11.P$1
D-6: JP79.D-1, TP13.P$1
D-7: JP92.D-1, TP15.P$1
D-8: JP105.D-1, TP17.P$1
D-9: JP118.D-1, TP19.P$1
D-10: JP131.D-1, TP21.P$1
D-11: JP144.D-1, TP23.P$1
D-12: JP157.D-1, TP25.P$1
D-13: JP170.D-1, TP27.P$1
D-14: JP183.D-1, TP29.P$1
D-15: JP196.D-1, TP31.P$1
D-16: JP209.D-1, TP33.P$1
D-17: JP222.D-1, TP35.P$1
D-18: JP235.D-1, TP37.P$1
D-19: JP248.D-1, TP39.P$1
D-20: JP261.D-1, TP41.P$1
D-21: JP274.D-1, TP43.P$1
D-22: JP287.D-1, TP45.P$1
D-23: JP300.D-1, TP47.P$1
D-24: JP313.D-1, TP49.P$1
D-25: JP326.D-1, TP51.P$1
D-26: JP339.D-1, TP53.P$1
D-27: JP352.D-1, TP55.P$1
EN1: R16.2, S2.4, U1.6
EN2: R17.2, S2.3, U1.5
EN3: R27.2, S4.3, U4.5
EN4: R26.2, S4.4, U4.6
EN5: R44.2, S6.3, U6.5
EN6: R43.2, S6.4, U6.6
EN7: R61.2, S8.3, U8.5
EN8: R60.2, S8.4, U8.6
EN9: R78.2, S10.3, U10.5
EN10: R77.2, S10.4, U10.6
EN11: R95.2, S12.3, U12.5
EN12: R94.2, S12.4, U12.6
EN13: R112.2, S14.3, U14.5
EN14: R111.2, S14.4, U14.6
EN15: R129.2, S16.3, U16.5
EN16: R128.2, S16.4, U16.6
EN17: R146.2, S18.3, U18.5
EN18: R145.2, S18.4, U18.6
EN19: R163.2, S20.3, U20.5
EN20: R162.2, S20.4, U20.6
EN21: R180.2, S22.3, U22.5
EN22: R179.2, S22.4, U22.6
EN23: R197.2, S24.3, U24.5
EN24: R196.2, S24.4, U24.6
EN25: R214.2, S26.3, U26.5
EN26: R213.2, S26.4, U26.6
EN27: R231.2, S28.3, U28.5
EN28: R230.2, S28.4, U28.6
EN29: R248.2, S30.3, U30.5
EN30: R247.2, S30.4, U30.6
EN31: R265.2, S32.3, U32.5
EN32: R264.2, S32.4, U32.6
EN33: R282.2, S34.3, U34.5
EN34: R281.2, S34.4, U34.6
EN35: R299.2, S36.3, U36.5
EN36: R298.2, S36.4, U36.6
EN37: R316.2, S38.3, U38.5
EN38: R315.2, S38.4, U38.6
EN39: R333.2, S40.3, U40.5
EN40: R332.2, S40.4, U40.6
EN41: R350.2, S42.3, U42.5
EN42: R349.2, S42.4, U42.6
EN43: R367.2, S44.3, U44.5
EN44: R366.2, S44.4, U44.6
EN45: R384.2, S46.3, U46.5
EN46: R383.2, S46.4, U46.6
EN47: R401.2, S48.3, U48.5
EN48: R400.2, S48.4, U48.6
EN49: R418.2, S50.3, U50.5
EN50: R417.2, S50.4, U50.6
EN51: R435.2, S52.3, U52.5
EN52: R434.2, S52.4, U52.6
EN53: R452.2, S54.3, U54.5
EN54: R451.2, S54.4, U54.6
EN55: R469.2, S56.3, U56.5
EN56: R468.2, S56.4, U56.6
GND: C1.2, C2.2, C3.2, C4.2, C5.2, JP1.GND1, JP2.2, JP3.2, JP4.2, JP5.1, JP6.1, JP7.2, JP8.1, JP9.1, JP10.1, R1.1, R3.1, R4.1, R5.2, R6.1, R7.2, R8.2, S1.3, S2.1, S2.2, SJ1.1, SJ2.1, SJ5.3, U1.8, U1.EP, U2.3, U2.EP, U2.EP1, U2.EP2, U2.EP3, U2.EP4
GND1: C6.2, C7.2, C8.2, C9.2, C10.2, JP14.GND1, JP15.1, JP16.1, JP18.1, JP19.2, JP20.2, JP21.1, JP22.1, JP23.2, JP26.2, R21.2, R22.2, R25.2, R28.1, R29.1, R31.1, R33.1, S3.3, S4.1, S4.2, SJ6.1, SJ9.1, SJ10.3, U3.3, U3.EP, U3.EP1, U3.EP2, U3.EP3, U3.EP4, U4.8, U4.EP
GND2: C11.2, C12.2, C13.2, C14.2, C15.2, JP27.GND1, JP28.1, JP29.1, JP31.1, JP32.2, JP33.2, JP34.1, JP35.1, JP36.2, JP39.2, R38.2, R39.2, R42.2, R45.1, R46.1, R48.1, R50.1, S5.3, S6.1, S6.2, SJ11.1, SJ14.1, SJ15.3, U5.3, U5.EP, U5.EP1, U5.EP2, U5.EP3, U5.EP4, U6.8, U6.EP
GND3: C16.2, C17.2, C18.2, C19.2, C20.2, JP40.GND1, JP41.1, JP42.1, JP44.1, JP45.2, JP46.2, JP47.1, JP48.1, JP49.2, JP52.2, R55.2, R56.2, R59.2, R62.1, R63.1, R65.1, R67.1, S7.3, S8.1, S8.2, SJ16.1, SJ19.1, SJ20.3, U7.3, U7.EP, U7.EP1, U7.EP2, U7.EP3, U7.EP4, U8.8, U8.EP
GND4: C21.2, C22.2, C23.2, C24.2, C25.2, JP53.GND1, JP54.1, JP55.1, JP57.1, JP58.2, JP59.2, JP60.1, JP61.1, JP62.2, JP65.2, R72.2, R73.2, R76.2, R79.1, R80.1, R82.1, R84.1, S9.3, S10.1, S10.2, SJ21.1, SJ24.1, SJ25.3, U9.3, U9.EP, U9.EP1, U9.EP2, U9.EP3, U9.EP4, U10.8, U10.EP
GND5: C26.2, C27.2, C28.2, C29.2, C30.2, JP66.GND1, JP67.1, JP68.1, JP70.1, JP71.2, JP72.2, JP73.1, JP74.1, JP75.2, JP78.2, R89.2, R90.2, R93.2, R96.1, R97.1, R99.1, R101.1, S11.3, S12.1, S12.2, SJ26.1, SJ29.1, SJ30.3, U11.3, U11.EP, U11.EP1, U11.EP2, U11.EP3, U11.EP4, U12.8, U12.EP
GND6: C31.2, C32.2, C33.2, C34.2, C35.2, JP79.GND1, JP80.1, JP81.1, JP83.1, JP84.2, JP85.2, JP86.1, JP87.1, JP88.2, JP91.2, R106.2, R107.2, R110.2, R113.1, R114.1, R116.1, R118.1, S13.3, S14.1, S14.2, SJ31.1, SJ34.1, SJ35.3, U13.3, U13.EP, U13.EP1, U13.EP2, U13.EP3, U13.EP4, U14.8, U14.EP
GND7: C36.2, C37.2, C38.2, C39.2, C40.2, JP92.GND1, JP93.1, JP94.1, JP96.1, JP97.2, JP98.2, JP99.1, JP100.1, JP101.2, JP104.2, R123.2, R124.2, R127.2, R130.1, R131.1, R133.1, R135.1, S15.3, S16.1, S16.2, SJ36.1, SJ39.1, SJ40.3, U15.3, U15.EP, U15.EP1, U15.EP2, U15.EP3, U15.EP4, U16.8, U16.EP
GND8: C41.2, C42.2, C43.2, C44.2, C45.2, JP105.GND1, JP106.1, JP107.1, JP109.1, JP110.2, JP111.2, JP112.1, JP113.1, JP114.2, JP117.2, R140.2, R141.2, R144.2, R147.1, R148.1, R150.1, R152.1, S17.3, S18.1, S18.2, SJ41.1, SJ44.1, SJ45.3, U17.3, U17.EP, U17.EP1, U17.EP2, U17.EP3, U17.EP4, U18.8, U18.EP
GND9: C46.2, C47.2, C48.2, C49.2, C50.2, JP118.GND1, JP119.1, JP120.1, JP122.1, JP123.2, JP124.2, JP125.1, JP126.1, JP127.2, JP130.2, R157.2, R158.2, R161.2, R164.1, R165.1, R167.1, R169.1, S19.3, S20.1, S20.2, SJ46.1, SJ49.1, SJ50.3, U19.3, U19.EP, U19.EP1, U19.EP2, U19.EP3, U19.EP4, U20.8, U20.EP
GND10: C51.2, C52.2, C53.2, C54.2, C55.2, JP131.GND1, JP132.1, JP133.1, JP135.1, JP136.2, JP137.2, JP138.1, JP139.1, JP140.2, JP143.2, R174.2, R175.2, R178.2, R181.1, R182.1, R184.1, R186.1, S21.3, S22.1, S22.2, SJ51.1, SJ54.1, SJ55.3, U21.3, U21.EP, U21.EP1, U21.EP2, U21.EP3, U21.EP4, U22.8, U22.EP
GND11: C56.2, C57.2, C58.2, C59.2, C60.2, JP144.GND1, JP145.1, JP146.1, JP148.1, JP149.2, JP150.2, JP151.1, JP152.1, JP153.2, JP156.2, R191.2, R192.2, R195.2, R198.1, R199.1, R201.1, R203.1, S23.3, S24.1, S24.2, SJ56.1, SJ59.1, SJ60.3, U23.3, U23.EP, U23.EP1, U23.EP2, U23.EP3, U23.EP4, U24.8, U24.EP
GND12: C61.2, C62.2, C63.2, C64.2, C65.2, JP157.GND1, JP158.1, JP159.1, JP161.1, JP162.2, JP163.2, JP164.1, JP165.1, JP166.2, JP169.2, R208.2, R209.2, R212.2, R215.1, R216.1, R218.1, R220.1, S25.3, S26.1, S26.2, SJ61.1, SJ64.1, SJ65.3, U25.3, U25.EP, U25.EP1, U25.EP2, U25.EP3, U25.EP4, U26.8, U26.EP
GND13: C66.2, C67.2, C68.2, C69.2, C70.2, JP170.GND1, JP171.1, JP172.1, JP174.1, JP175.2, JP176.2, JP177.1, JP178.1, JP179.2, JP182.2, R225.2, R226.2, R229.2, R232.1, R233.1, R235.1, R237.1, S27.3, S28.1, S28.2, SJ66.1, SJ69.1, SJ70.3, U27.3, U27.EP, U27.EP1, U27.EP2, U27.EP3, U27.EP4, U28.8, U28.EP
GND14: C71.2, C72.2, C73.2, C74.2, C75.2, JP183.GND1, JP184.1, JP185.1, JP187.1, JP188.2, JP189.2, JP190.1, JP191.1, JP192.2, JP195.2, R242.2, R243.2, R246.2, R249.1, R250.1, R252.1, R254.1, S29.3, S30.1, S30.2, SJ71.1, SJ74.1, SJ75.3, U29.3, U29.EP, U29.EP1, U29.EP2, U29.EP3, U29.EP4, U30.8, U30.EP
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

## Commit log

2015-12-08 Initial commit of hardware.
    [sparkfun-battery-babysitter.brd, sparkfun-battery-babysitter.sch]
2015-12-09 Adding a few PROD_ID's
    [sparkfun-battery-babysitter.brd, sparkfun-battery-babysitter.sch]
2015-12-09 Swapping out DIP switch for larger variant
    [sparkfun-battery-babysitter.brd, sparkfun-battery-babysitter.sch]
2015-12-09 Adding silk to EN pin DIP switch positions
    [sparkfun-battery-babysitter.brd]
2015-12-09 Nudging sparkfun logo
    [sparkfun-battery-babysitter.brd, sparkfun-battery-babysitter.sch]
2015-12-09 Adding PROD_ID's for new components
    [sparkfun-battery-babysitter.brd, sparkfun-battery-babysitter.sch]
2016-02-29 Adding SJ5, to set power LED to PWR or PGOOD.
    [sparkfun-battery-babysitter.brd, sparkfun-battery-babysitter.sch]
2016-02-29 Re-arranging some silk
    [sparkfun-battery-babysitter.brd]
2016-03-04 Break out D+/D-, silkscreen fixes
    [sparkfun-battery-babysitter.brd, sparkfun-battery-babysitter.sch]
2016-03-04 Small silk fixes after run through checklist
    [Engineer-check-v10.xls, sparkfun-battery-babysitter.brd, sparkfun-battery-babysitter.sch]
2016-03-09 Reverting version to v02 - proto round 2
    [sparkfun-battery-babysitter.brd, sparkfun-battery-babysitter.sch]
2016-04-04 Moving some silk, nudging a via, upping to v10
    [Engineer-check-v10.xls, sparkfun-battery-babysitter.brd, sparkfun-battery-babysitter.sch]
2016-04-04 Fixing 1.8V OUT silkscreen
    [sparkfun-battery-babysitter.brd]
2016-04-04 Updating DIP switch silkscreen
    [sparkfun-battery-babysitter.brd, sparkfun-battery-babysitter.sch]
2016-04-05 Increasing line width on BQ27441-G1 package.
    [sparkfun-battery-babysitter.brd, sparkfun-battery-babysitter.sch]
2016-04-06 created panel v10
    [sparkfun-battery-babysitter-panel-v10.brd]
2016-06-23 Removing temp library, and updating libs in eagle files.
    [sparkfun-battery-babysitter.brd, sparkfun-battery-babysitter.sch]
2016-06-23 Squashed 'Libraries/Arduino/' content from commit 8eda0d6
    git-subtree-dir: Libraries/Arduino
    git-subtree-split: 8eda0d6754c3a09a8a509ac4fc0d03b2e4acdd93
2016-11-29 Values Added to 3 Part on .brd/.sch
    USB-AB-MICRO-SMD_V03
    SW_DIP-2_SMD
    RIGHT_ANGLE_SLIDE_SWITCH_SMD
    [sparkfun-battery-babysitter.brd, sparkfun-battery-babysitter.sch]
2024-12-12 Fixes BOM for Battery Babysitter
    [sparkfun-battery-babysitter_bom.csv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]
2025-01-07 Removes unnecessary files
    [sparkfun-battery-babysitter_bom.csv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]

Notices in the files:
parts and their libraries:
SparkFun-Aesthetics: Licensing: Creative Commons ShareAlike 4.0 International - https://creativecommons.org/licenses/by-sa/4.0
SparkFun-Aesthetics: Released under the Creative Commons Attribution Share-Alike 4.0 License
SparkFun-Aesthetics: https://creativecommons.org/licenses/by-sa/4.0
